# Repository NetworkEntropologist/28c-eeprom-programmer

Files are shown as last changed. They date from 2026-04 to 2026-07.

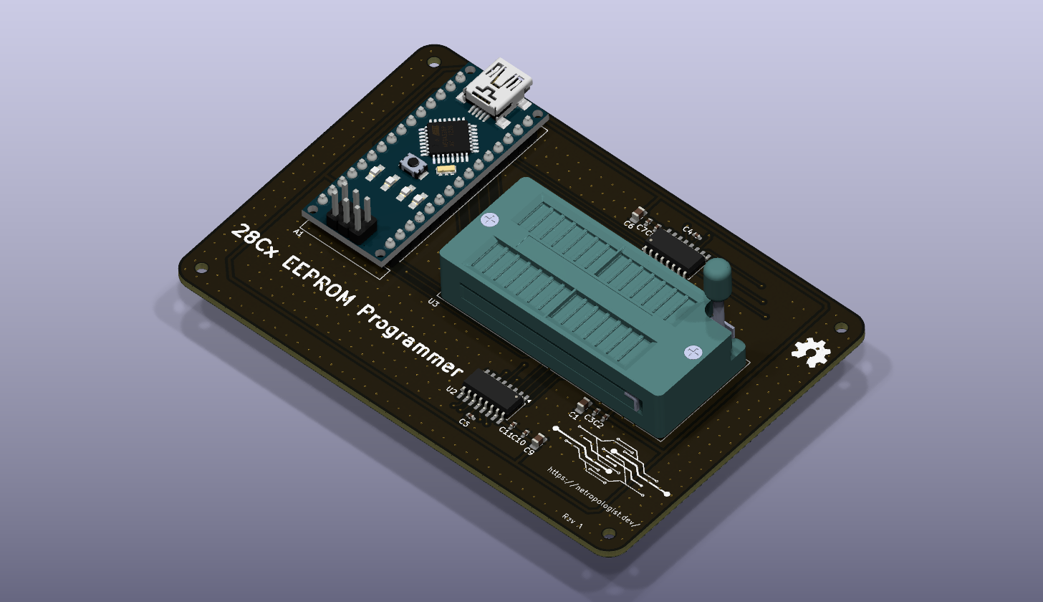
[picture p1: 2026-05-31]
hardware/smd/rom-programmer.png

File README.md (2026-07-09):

# 28c-eeprom-programmer





<a href="https://www.buymeacoffee.com/thenetworkentropologist" target="_blank">Buy Me a Coffee</a>

A parallel EEPROM programmer for the 28C family, built around an Arduino Nano. Simply drop an EEPROM into the ZIF socket, connect the Nano over USB, and burn a ROM image onto it from your computer.

If you've watched Ben Eater's 8-bit computer series, this will look familiar. That's where the idea came from. I wanted a proper PCB instead of the breadboard version, and a ZIF socket so I'm not bending chip pins every time I swap an EEPROM.

## About this project

This is a personal project that I'm putting it up in case someone else finds it useful or interesting. I'm not planning to write full documentation right now, and I might not ever get to it. So for the moment, the board files and the code are the documentation.

If you find a bug, or you get it working with a chip I haven't tested, feel free to open an issue or a pull request. Just don't expect a fast reply — this is a side thing I work on when I have time.

## Where this came from

For a number of years I have been interested in retrocomputing, when one day I stumbled across [Ben Eater's YouTube channel](https://www.youtube.com/@BenEater). Following his series on espeially the [6502 breadboard computer project](https://youtube.com/playlist?list=PLowKtXNTBypFbtuVMUVXNR0z1mu7dp7eH) I wanted to start building this for myself, or rather using this as inspiration to design and build my own 6501 computer, and this EEPROM Programmer seemed like the best place to start, as this would be a required tool for pretty much everything else. 

I have to mention at this point, two other related projects that I used heavily for both inspiration, as well as for insights into how other creators tackled this:

- **Ben Eater's [eeprom-programmer](https://github.com/beneater/eeprom-programmer)** — the one from his 8-bit computer series. Same core idea as mine: an Arduino driving the address lines through a pair of 74HC595 shift registers. If you've never seen it, watch his video first. He explains the whole thing better than I can here.
- **Erik van Zijst's [eeprom](https://github.com/erikvanzijst/eeprom)** — an Arduino Uno shield with a KiCad board and an interactive Python client. Seeing someone take the breadboard version and turn it into a proper PCB with host software was a big part of what pushed me to do my own board.

So thanks to both of them. My version borrows ideas from each and mixes in what I wanted out of it.

## Does it actually work?

Short answer? Yes. First test on the PCB, after soldering it, was to attempt burning a copy of Wozmon onto the IC, which checked out byte exact. Turns out Wozmon is a really great test, as the contents is very well known and documented all over the internet.

## What it does

- Writes a ROM image to a 28C-family EEPROM over USB serial
- Reads the chip back so you can verify the write

## Supported chips

Anything in the 28C family that follows the 28C64 pinout should work. That being said, I've only tested it with a 28C64 so far. So treat everything else as *should work* rather than *known good*. If you run it with a 28C16 or 28C256, I'd like to hear how it goes.

## Hardware / BOM

The main parts, leaving out the passives:

- 1x Arduino Nano driving the entire process
- 2x 74HC595 shift registers (serial in, parallel out) driving the address lines
- 1x 28-pin ZIF socket

## Repo layout

- `hardware/` — the full KiCad project (schematic and PCB)
- `firmware/` — the Arduino firmware for the Nano
- `software/` — the host-side Python that talks to the board

## Getting boards made

The KiCad project lives in `hardware/`. Open it in KiCad, export the Gerbers, and send them off to whichever fab you like. I used JLCPCB with a purple soldermask and had no trouble — DRC passed and the boards were fine.

## Flashing the firmware

The firmware in `firmware/` was written with [PlatformIO](https://platformio.org/), not the regular Arduino IDE. So the easiest way to build and upload is with PlatformIO (either the VS Code extension or the CLI). Open the `firmware/` folder as a PlatformIO project, plug in the Nano, and run the upload.

If you're using an older Nano clone, you may need to point the build at the old bootloader, otherwise the upload will fail. That's set in the `platformio.ini`.

This assumes you've used PlatformIO before. If you haven't, their [docs](https://docs.platformio.org/) cover installing it and uploading to a board better than I could here.

## Using the software

The host software is in `software/` and it's written in Python. Fair warning: it's still very much a work in progress. Because of that I'm not going to write down a fixed set of commands here that might change next week. Have a look in the `software/` folder and read the code to see how it works for now.

I'm planning to rewrite this side in Rust later on, so expect it to change.

## License

- Hardware (everything in `hardware/`): [CERN-OHL-S v2](https://ohwr.org/cern_ohl_s_v2.txt)
- Firmware and software (`firmware/` and `software/`): [MIT](https://opensource.org/licenses/MIT)

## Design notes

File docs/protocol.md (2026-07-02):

# Serial Protocol - EEPROM Programmer

## Overview

The protocol uses a simple frame-based structure with the following components:
- **START**: Frame start marker
- **LENGTH**: Number of payload bytes that follow (command + data)
- **COMMAND**: The operation to perform (READ, WRITE, etc.)
- **PAYLOAD**: Command-specific data (addresses, values, etc.)

## Packet Structure

### General Frame Format
```
[START] [LENGTH] [CMD] [PAYLOAD...]
```

| Field | Size | Value | Notes |
|---|---|---|---|
| START | 1 byte | 0x01 | Frame start marker |
| LENGTH | 1 byte | variable | Number of bytes following (CMD + PAYLOAD) |
| CMD | 1 byte | variable | Command byte |
| PAYLOAD | variable | variable | Command-specific data |

---

## Commands

### READ - Read a single byte from EEPROM

#### Request
```
[0x01] [0x03] [0x52] [ADDR_H] [ADDR_L]
```

| Byte | Value | Notes |
|---|---|---|
| B0 | 0x01 | START |
| B1 | 0x03 | LENGTH (command + 2 address bytes) |
| B2 | 0x52 | READ command ('R') |
| B3 | - | Address high byte |
| B4 | - | Address low byte |

#### Response
```
[0x01] [0x03] [ADDR_H] [ADDR_L] [DATA]
```

| Byte | Value | Notes |
|---|---|---|
| B0 | 0x01 | START |
| B1 | 0x03 | LENGTH (2 address bytes + 1 data byte) |
| B2 | - | Address high byte (echoed) |
| B3 | - | Address low byte (echoed) |
| B4 | - | Data byte read from EEPROM |

**Example**: Read address 0x0001
- Request: `01 03 52 00 01`
- Response: `01 03 00 01 A9` (reads value 0xA9 from address 0x0001)

---

### WRITE - Write a single byte to EEPROM

#### Request
```
[0x01] [0x04] [0x57] [ADDR_H] [ADDR_L] [DATA]
```

| Byte | Value | Notes |
|---|---|---|
| B0 | 0x01 | START |
| B1 | 0x04 | LENGTH (command + 2 address bytes + 1 data byte) |
| B2 | 0x57 | WRITE command ('W') |
| B3 | - | Address high byte |
| B4 | - | Address low byte |
| B5 | - | Data byte to write |

#### Response
```
[0x01] [0x03] [ADDR_H] [ADDR_L] [DATA]
```

| Byte | Value | Notes |
|---|---|---|
| B0 | 0x01 | START |
| B1 | 0x03 | LENGTH (2 address bytes + 1 data byte) |
| B2 | - | Address high byte (echoed) |
| B3 | - | Address low byte (echoed) |
| B4 | - | Data byte written |

**Example**: Write 0xA9 to address 0x0001
- Request: `01 04 57 00 01 A9`
- Response: `01 03 00 01 A9` (confirms write)

---

## Error Response

### Error Format
```
[0x06] [0x69] [ERROR_CODE]
```

| Byte | Value | Notes |
|---|---|---|
| B0 | 0x06 | ACK (acknowledgment) |
| B1 | 0x69 | Error marker ('i') |
| B2 | - | Error code |

### Error Codes
| Code | Name | Meaning |
|---|---|---|
| 0 | OK | No error |
| 1 | RESET | Reset condition |
| 2 | CORRUPT | Corrupted data received |
| 3 | UNEXPECTED | Unexpected command or state |
| 4 | UNKNOWN | Unknown error |
| 5 | NOTIMPLEMENTED | Command not yet implemented |

---

## Notes

- All multi-byte values (addresses) are in **big-endian** format (high byte first)
- The LENGTH field includes the command byte plus all payload bytes
- Responses echo back the address for verification purposes
- Future commands (DUMP, ERASE, LOAD) follow the same frame structure with command-specific payloads

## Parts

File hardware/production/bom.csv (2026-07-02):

Designator | Footprint | Quantity | Value | LCSC Part #
C1, C6, C9 | 0805 | 3 | 1uF
C10, C11, C2, C3, C4, C5, C7, C8 | 0402 | 8 | 0.1uF
U1, U2 | SOP-16_4.55x10.3mm_P1.27mm | 2 | 74HC595

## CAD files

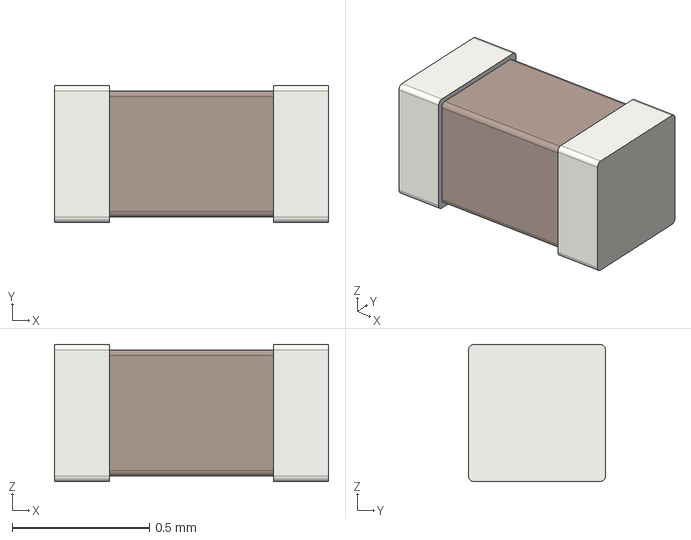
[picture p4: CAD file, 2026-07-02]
3d models/C_0402_1005Metric.step
1.00 x 0.5 x 0.5 mm

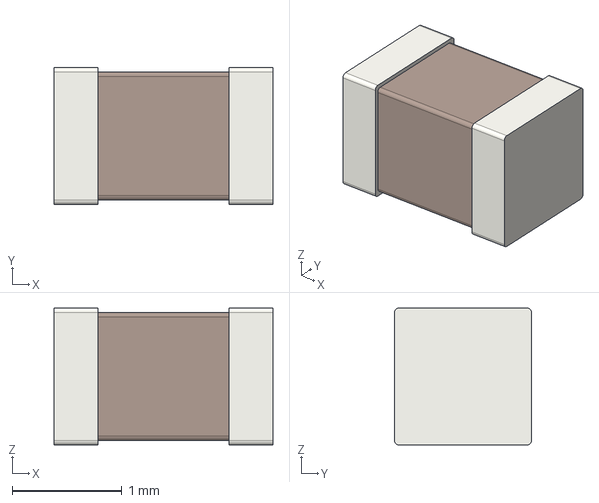
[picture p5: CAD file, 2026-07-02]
3d models/C_0805_2012Metric.step
2.00 x 1.25 x 1.25 mm

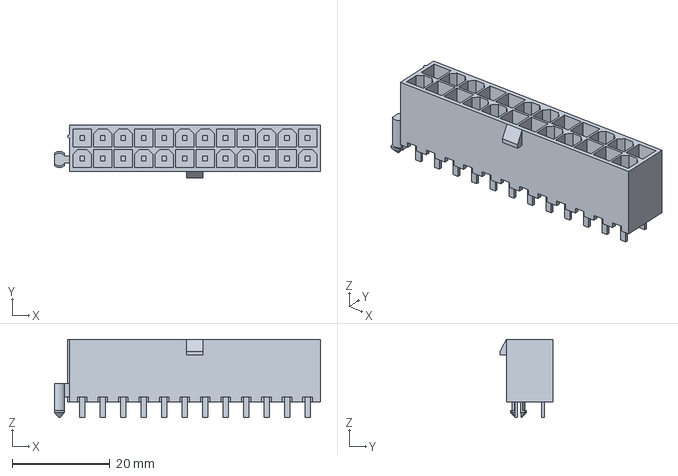
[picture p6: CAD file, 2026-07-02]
3d models/zif.step
54.6 x 10.9 x 16.0 mm

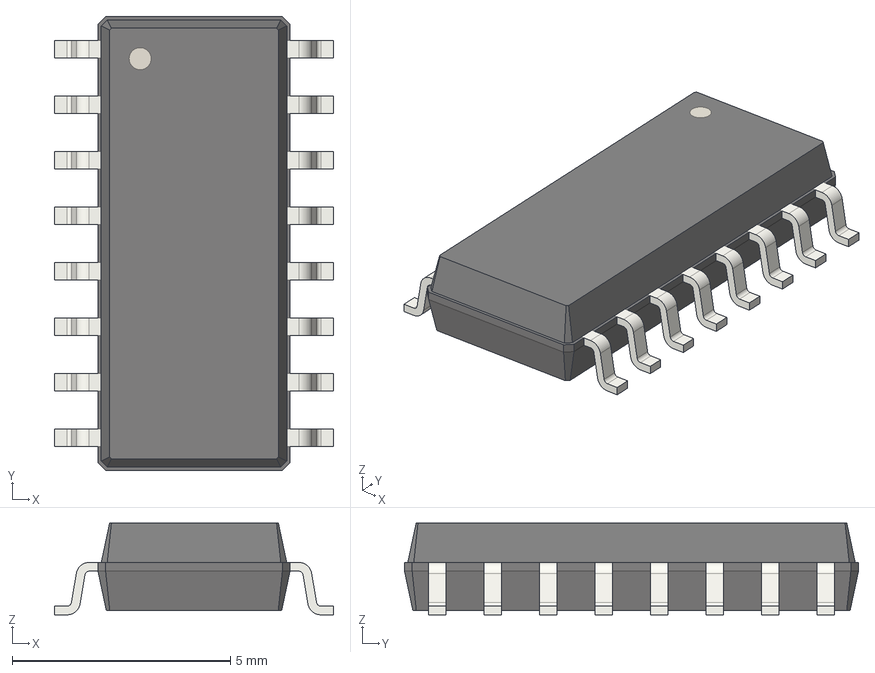
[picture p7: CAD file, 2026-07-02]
3d models/SOP-16_4.4x10.4mm_P1.27mm.step
6.40 x 10.4 x 2.10 mm

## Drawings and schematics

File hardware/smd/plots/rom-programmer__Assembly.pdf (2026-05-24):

1 | 2 | 3 | 4 | 5 | 6

A

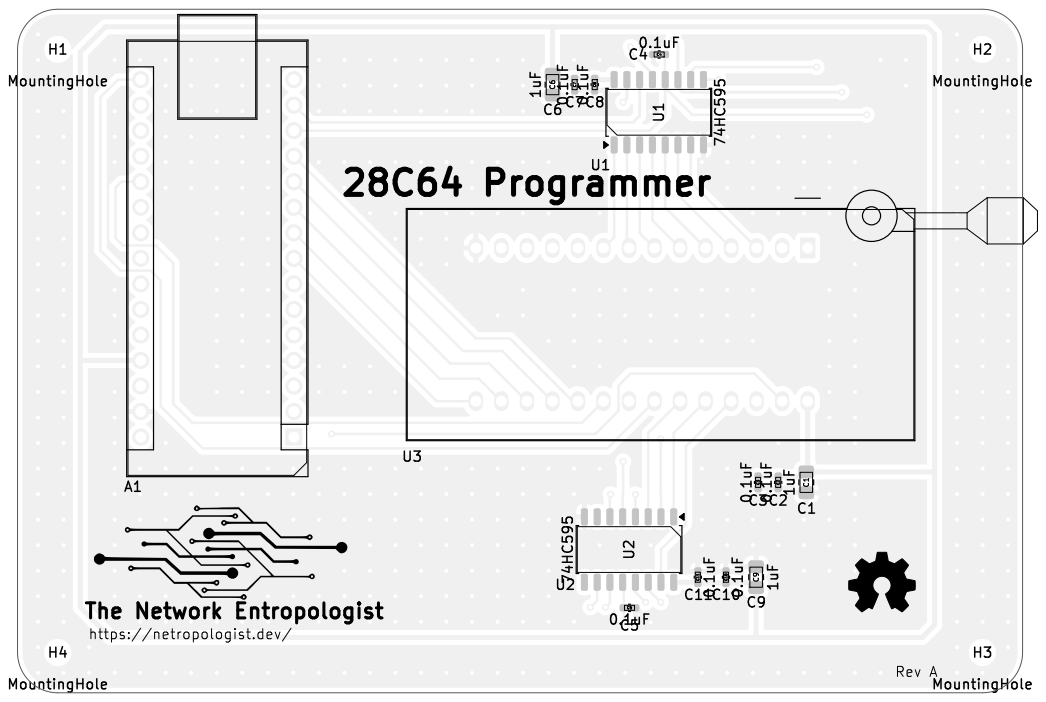
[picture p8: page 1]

A

A

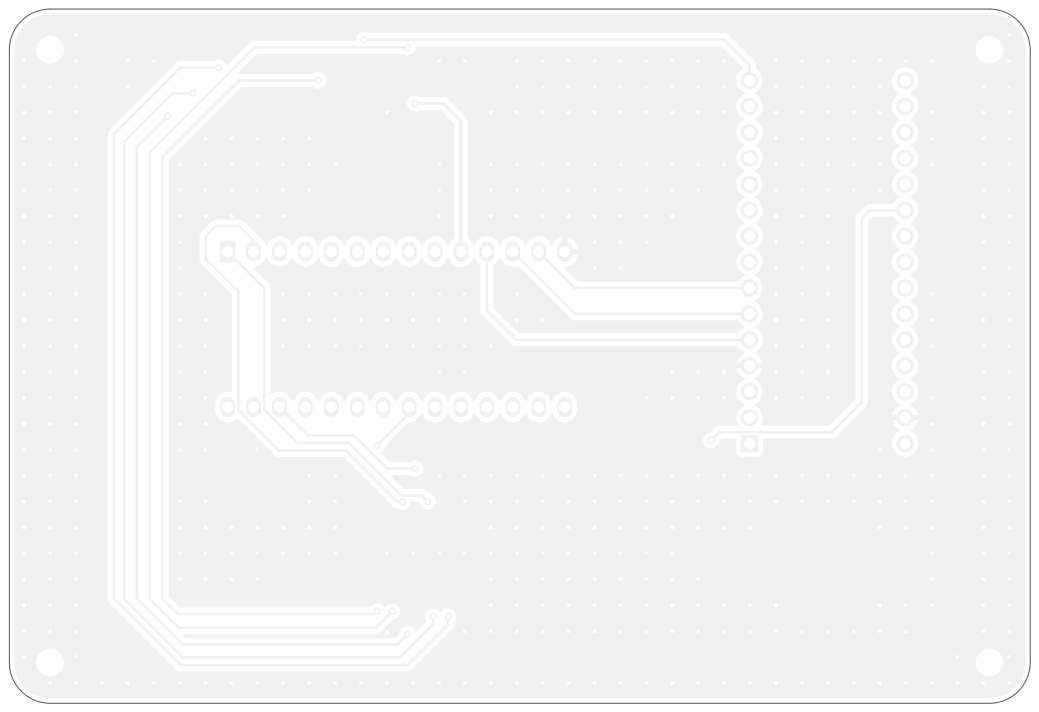
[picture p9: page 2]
D Date: KiCad; E.D.A. 9.0.7 Size: A4; Rev:; Id: /1 Title: File: rom-programmer.kicad_pcb Sheet: Black; And; White; BOT Board2Pdf:; Black; BOT -; Page 2/3

A

A

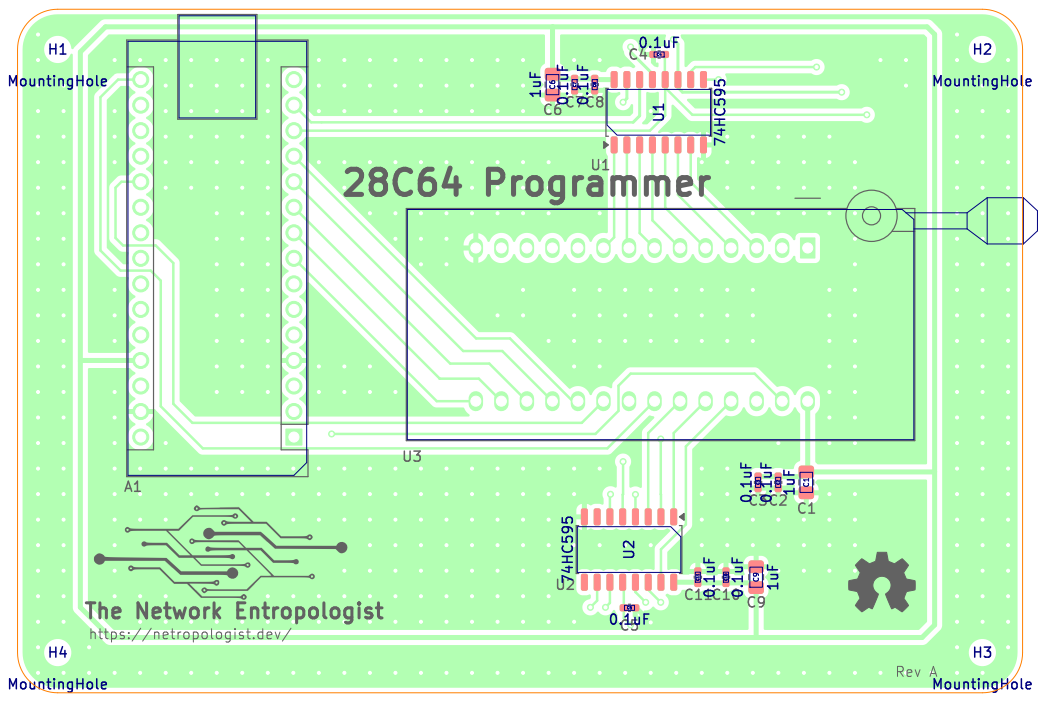
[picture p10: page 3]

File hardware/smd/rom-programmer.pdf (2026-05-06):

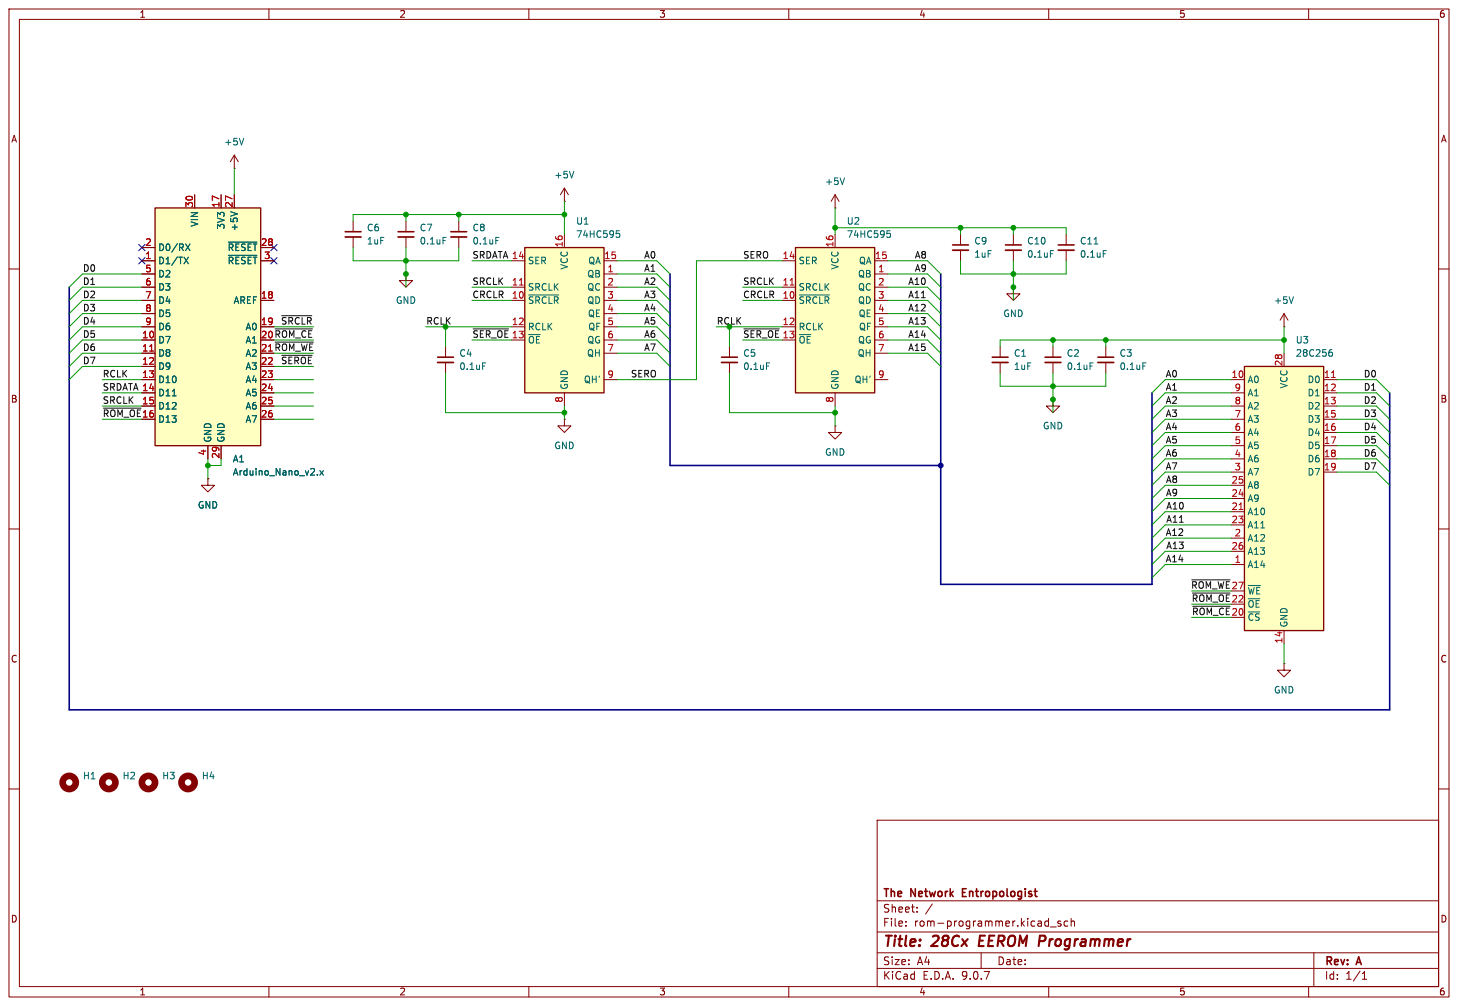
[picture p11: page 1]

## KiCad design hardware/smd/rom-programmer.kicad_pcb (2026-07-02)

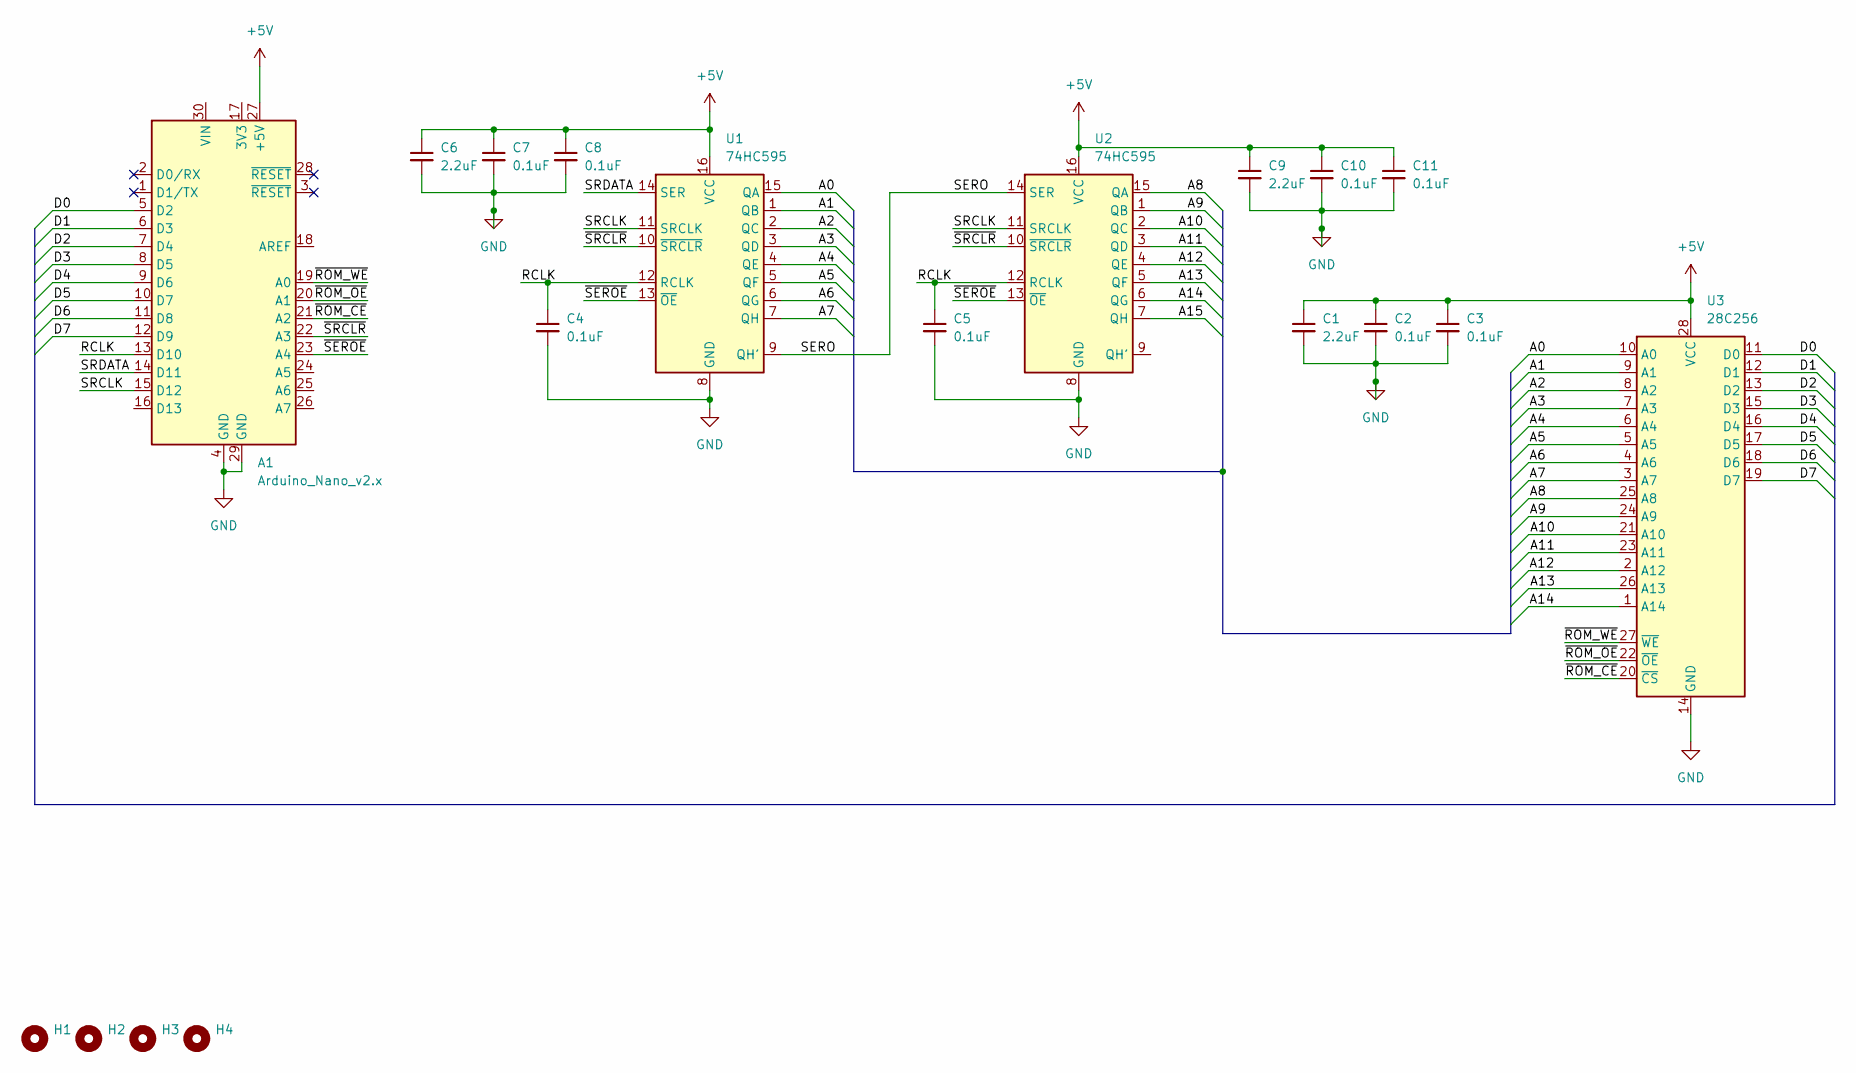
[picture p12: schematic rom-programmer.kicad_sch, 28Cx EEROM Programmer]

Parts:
A1: Arduino_Nano_v2.x; Arduino_Nano
C1, C6, C9: 2.2uF; C_0805_2012Metric_Pad1.18x1.45mm_HandSolder; Mouser SKU 187-CL21B104KCFWPJF
C2, C3, C4, C5, C7, C8, C10, C11: 0.1uF; C_0402_1005Metric_Pad0.74x0.62mm_HandSolder; Mouser SKU 187-CL05B104KO54PND
H1, H2, H3, H4: MountingHole; MountingHole_2.2mm_M2
U1, U2: 74HC595; SOP-16_4.55x10.3mm_P1.27mm; Mouser SKU 595-SN74HC595ANSR
U3: 28C256; DIP_Socket-28_W11.9mm_W12.7mm_W15.24mm_W17.78mm_W18.5mm_3M_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

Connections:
+5V: A1.27 (+5V), C1.1, C2.1, C3.1, C6.1, C7.1, C8.1, C9.1, C10.1, C11.1, U1.16 (VCC), U2.16 (VCC), U3.28 (VCC)
/A0: U1.15 (QA), U3.10 (A0)
/A1: U1.1 (QB), U3.9 (A1)
/A2: U1.2 (QC), U3.8 (A2)
/A3: U1.3 (QD), U3.7 (A3)
/A4: U1.4 (QE), U3.6 (A4)
/A5: U1.5 (QF), U3.5 (A5)
/A6: U1.6 (QG), U3.4 (A6)
/A7: U1.7 (QH), U3.3 (A7)
/A8: U2.15 (QA), U3.25 (A8)
/A9: U2.1 (QB), U3.24 (A9)
/A10: U2.2 (QC), U3.21 (A10)
/A11: U2.3 (QD), U3.23 (A11)
/A12: U2.4 (QE), U3.2 (A12)
/A13: U2.5 (QF), U3.26 (A13)
/A14: U2.6 (QG), U3.1 (A14)
/A15: U2.7 (QH)
/D0: A1.5 (D2), U3.11 (D0)
/D1: A1.6 (D3), U3.12 (D1)
/D2: A1.7 (D4), U3.13 (D2)
/D3: A1.8 (D5), U3.15 (D3)
/D4: A1.9 (D6), U3.16 (D4)
/D5: A1.10 (D7), U3.17 (D5)
/D6: A1.11 (D8), U3.18 (D6)
/D7: A1.12 (D9), U3.19 (D7)
/RCLK: A1.13 (D10), C4.1, C5.1, U1.12 (RCLK), U2.12 (RCLK)
/SERO: U1.9 (QH'), U2.14 (SER)
/SRCLK: A1.15 (D12), U1.11 (SRCLK), U2.11 (SRCLK)
/SRDATA: A1.14 (D11), U1.14 (SER)
/~ROM_CE: A1.21 (A2), U3.20 (~CS)
/~ROM_OE: A1.20 (A1), U3.22 (~OE)
/~ROM_WE: A1.19 (A0), U3.27 (~WE)
/~SEROE: A1.23 (A4), U1.13 (~OE), U2.13 (~OE)
/~SRCLR: A1.22 (A3), U1.10 (~SRCLR), U2.10 (~SRCLR)
GND: A1.4 (GND), A1.29 (GND), C1.2, C2.2, C3.2, C4.2, C5.2, C6.2, C7.2, C8.2, C9.2, C10.2, C11.2, U1.8 (GND), U2.8 (GND), U3.14 (GND)

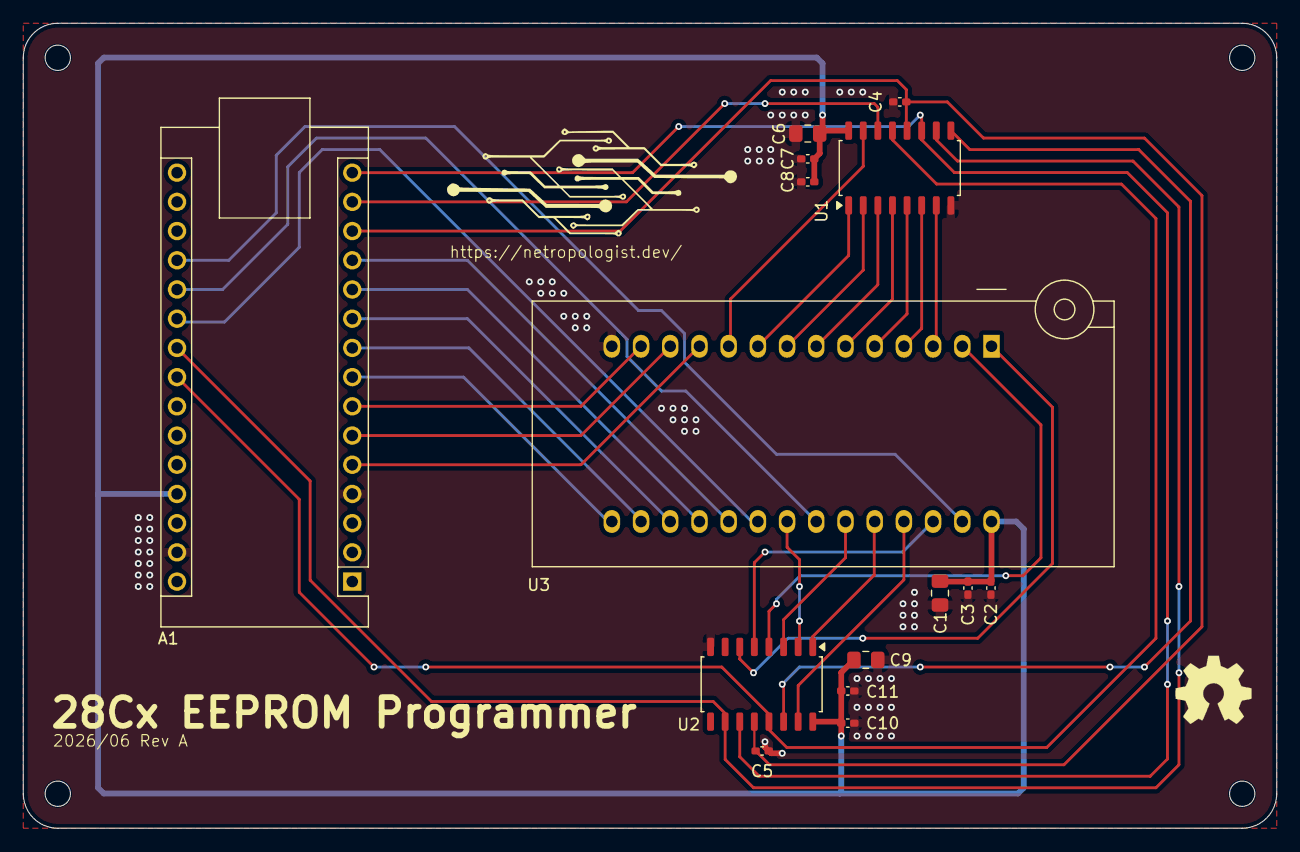
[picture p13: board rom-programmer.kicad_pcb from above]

Board: 2 copper layers, 109.0 x 70.0 mm, 19 parts (0 on the bottom side), 34 nets.

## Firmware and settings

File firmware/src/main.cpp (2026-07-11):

/**
 * @file main.cpp
 * @brief Arduino Nano firmware for 28Cx EEPROM programmer
 * @author The Network Entropologist
 * @version 0.1
 * @details Supports programming of 28C16, 28C64, 28C256, and 28C512 EEPROMs.
 *          Hardware: Arduino Nano with 74HC595 shift registers.
 *          Driven by Python control script.
 *          Inspired by https://github.com/beneater/eeprom-programmer
 *          Pin assignments and timing parameters are defined in include/defines.h.
 *          Update pin assignments based on your own hardware design.
 *          Update timing parameters as needed for reliable programming.
 *          Best to consult the datasheet of the specific EEPROM being programmed for timing requirements.
 *          Suggest 100us as a starting point for programming timing.
 * @license MIT License (See LICENSE-MIT file in project root)
 */

#include <Arduino.h>
#include "defines.h"
#include "eeprom.h"
#include "shiftregister.h"
#include "debugging.h"
#include "wozmon.h"
#include "serialio.h"

void setup() {
  
  Serial.begin(SERIAL_BAUD);

  setupEEPROMPins();

  // Setup the shift register control pins
  setupShiftRegisterPins();

  // Uncomment these lines to perform tests on device startup.
  // writeTest(0x00, 0x2000);
  // eraseTest(0x00, 0x2000);
  // delay(1000);
  // writeWozMon();
  // quickReadTest(0x00, 0x2000);

}

void loop() {

  if (Serial.available() > 0) {
    digitalWrite(ACTIVITY_LED, HIGH); // LED on to indicate a serial command is being processed

    byte buffer[MAX_PAYLOAD];

    const int len = serialReceive(buffer, sizeof(buffer), false);

    if (len > 0) {
      int command_valid = verifyCommand(buffer);
      if (command_valid != 0) { // Invalid command packet received
        sendErrorResponse();
      }
      else { // Valid command packet received
        processSerialCommand();
      }
    }

    digitalWrite(ACTIVITY_LED, LOW);
  
  }
  
}

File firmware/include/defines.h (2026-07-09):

/**
 * @file defines.h
 * @brief Pin definitions and timing constants for 28Cx EEPROM programmer
 * @details Configure these values based on your hardware design and EEPROM requirements.
 *          Pin assignments: Update based on your Arduino connections.
 *          Timing parameters: Consult the specific EEPROM datasheet for accurate values.
 */

#ifndef DEFINES_H
#define DEFINES_H

#define ACTIVITY_LED 13 // Arduino pin D13 connected to activity LED
#define MAX_PAYLOAD 8


// EEPROM Control Pins
#define ROM_WE 14 // Arduino pin D14 (A0) connected to EEPROM /WE (active low)
#define ROM_OE 15 // Arduino pin D15 (A1) connected to EEPROM /OE (active low)
#define ROM_CE 16 // Arduino pin D16 (A2) connected to EEPROM /CE (active low)

// EEPROM Data Pins
#define D0 2 // Arduino pin D2 connected to EEPROM D0
#define D7 9 // Arduino pin D9 connected to EEPROM D7

// 74HC595 Shift Register Control Pins
#define SRCLK 12 // Arduino pin D12 connected to 74HC595 SRCLK - pin 11
#define SRCLR 17 // Arduino pin D17 (A3) connected to 74HC595 SRCLR - pin 10 (active low)
#define RCLK 10 // Arduino pin D10 connected to 74HC595 RCLK - pin 12
#define SEROE 18 // Arduino pin D18 (A4) connected to 74HC595 SEROE - pin 13 (active low)
#define DATA 11 // Arduino pin D11 connected to 74HC595 SER - pin 14

// Timing Parameters
#define WRITE_DELAY 10 // Delay in microseconds for programming operations
#define READ_DELAY 1 // Delay in microseconds for read operations
#define ADDR_DELAY 1 // Delay in microseconds for address setup
#define DATA_DELAY 1 // Delay in microseconds for data setup
#define GEN_DELAY 10 // General delay in microseconds

// More timing parameters
#define tAS 1 // Address setup time in microseconds
#define tOES 1 // Output enable setup time in microseconds
#define tAH 5 // Address hold time in microseconds
#define tWP 10 // Write pulse width in microseconds
#define tDS 5 // Data setup time in microseconds (reverted to 5)
#define tDH 5 // Data hold time in microseconds
#define tOEH 1 // Output enable hold time in microseconds
#define tCS 1 // Chip select setup time in microseconds
#define tCH 1 // Chip select hold time in microseconds
#define tDB 5 // Device busy time in microseconds
// The datasheet specifies a tWC between 200us andd 1ms. Setting this to 3ms to give a good margin for reliable
// operation, as anything lower starts introducing glitches and incorrectly written bytes.
#define tWC 300 // Write cycle time in microseconds

//#define MAX_ADDRESS 0x7FFF // Maximum address for 28C512 EEPROM (32KB)
#define MAX_ADDRESS 0x2000 // Maximum address for 28C64 EEPROM (8KB)

// Debug parameters
#define DEBUG_DATA 0xA9 // Test data value to write during address test loop
#define DEBUG_DELAY 250 // Delay in milliseconds for debugging loops to allow visual verification of blinkenlights

// Serial comms parameters
#define SERIAL_BAUD 115200 // Baud rate for serial communication with Python control script

#endif // DEFINES_H

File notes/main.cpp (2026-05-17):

#include <Arduino.h>

#define LED_PIN 13
#define MAX_PAYLOAD 16 // Max serial payload - setting to 16 bytes for development

int inByte = 0;        // incoming serial byte
char inChar = ' ';     // incoming serial char
bool connected = false;

void setup() {
  // put your setup code here, to run once:

  pinMode(LED_PIN, OUTPUT);  // initialize the LED pin as an output
  digitalWrite(LED_PIN, LOW); // turn the LED off by making the voltage LOW

  // start serial port at 115200 bps:
  Serial.begin(115200);
  Serial.setTimeout(120000L); // set the timeout to 2 minutes
  while (!Serial) {
    ;  // wait for serial port to connect. Needed for native USB port only
  }

}

void loop() {

  if (Serial.available() > 0) {
    // byte buf[1 + MAX_PAYLOAD]; // buffer for incoming serial data]
    // digitalWrite(LED_PIN, HIGH); // Turn on the LED while processing serial data

    // const int len = receive(buf, sizeof(buf), false);
    
    // if (len > 0) {
    //   // For starters, let's just echo the received data back
    //   send(buf, len, false);
    // }

    // For development, just read the incoming byte and echo it back
    inByte = Serial.read();
    inChar = (char)inByte;
    Serial.print(inChar);

    digitalWrite(LED_PIN, LOW); // Turn off the LED after processing serial data

}

}

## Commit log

2026-04-27 Can now shift out addresses and set data lines.
    [pins.xlsx]
2026-04-30 It can write bytes!
    [rom-programmer.kicad_pcb, rom-programmer.kicad_sch]
2026-05-01 Omg! I just managed to successfully burn Wozmon!!
    [debugging.cpp, defines.h, eeprom.cpp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]
2026-05-05 Erase and timing seems to work correctly and reliably now
    [rom-programmer.kicad_pcb, rom-programmer.kicad_sch]
2026-05-06 Added schematic PDF
    [rom-programmer.kicad_sch]
2026-05-24 Serial comms finally working!
    [rom-programmer.kicad_pcb, rom-programmer.kicad_sch]
2026-06-14 Can now read a single byte from the CLI
    [C_0402_1005Metric.step, C_0805_2012Metric.step, SOP-16_4.4x10.4mm_P1.27mm.step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]
2026-07-02 Writing files works
    [ASCII.xlsx, bom.csv, designators.csv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]
2026-07-09 Hardware PCB working as expected
2026-07-09 Cleaning and updating README
    [breadboard-pinout.xlsx]
2026-07-09 Cleaning up
    [rom-programmer copy.kicad_pcb, rom-programmer.kicad_pcb, rom-programmer.kicad_sch]
2026-07-11 Solved read/write performance bug
    [main.cpp, serialio.cpp]

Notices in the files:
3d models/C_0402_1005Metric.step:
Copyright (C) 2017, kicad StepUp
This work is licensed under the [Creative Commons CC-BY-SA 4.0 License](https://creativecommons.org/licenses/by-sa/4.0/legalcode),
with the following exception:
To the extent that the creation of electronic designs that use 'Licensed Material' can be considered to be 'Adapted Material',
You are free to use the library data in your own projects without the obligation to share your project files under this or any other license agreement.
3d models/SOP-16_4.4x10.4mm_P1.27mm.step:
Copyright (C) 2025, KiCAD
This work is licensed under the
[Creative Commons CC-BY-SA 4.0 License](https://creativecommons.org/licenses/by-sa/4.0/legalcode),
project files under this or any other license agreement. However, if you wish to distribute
